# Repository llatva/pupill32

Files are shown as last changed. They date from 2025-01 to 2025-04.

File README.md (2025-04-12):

# pu(rple)pill32
## Compact and inexpensive USB-C development board for PY32F030 (TSSOP20) 32-bit MCU

RevA had some glitches, please refer to changelog in the revB schematic or below.
RevB tested to be functional, and can be flash-programmed over USB (see bootloader access below).

## Features

* development/evaluation board for Pyua PY32F030F1xP6 MCU (TSSOP20)
* USB serial (CH340N, ESD protection)
* USB bootloader support (e.g. puyaisp.py from MCU-Flash-Tools /1/)
* 48 MHz operation with internal oscillator
* option for 32.768 kHz crystal (if used, pins PA9 and PA10 reserved)
* all peripheral pins available
* SWD header for programming (by using USB bootloader for flashing, those pins can be configured for other purposes**)
* 3V3 linear regulator; 3V3 logic levels
* powered from USB (SMD fuse for overcurrent protection)
* PWR LED and user-programmable USR led (activated by solder bridge)
* RESET and BOOT buttons

**) In that case, if you don't need pull-ups for your signals, do not populate R11-R12.

## Bootloader access

USB UART is connected to PA2/PA3 (TX/RX). To access bootloader (e.g. puyaisp.py /1/, USB-to-serial), either

* Disconnect USB cable, press and hold BOOT button then connect the cable.

OR 

* Connect USB cable, press and hold BOOT button and press and release RESET button

/1/ [https://github.com/wagiminator/MCU-Flash-Tools]

## Images

top
bottom

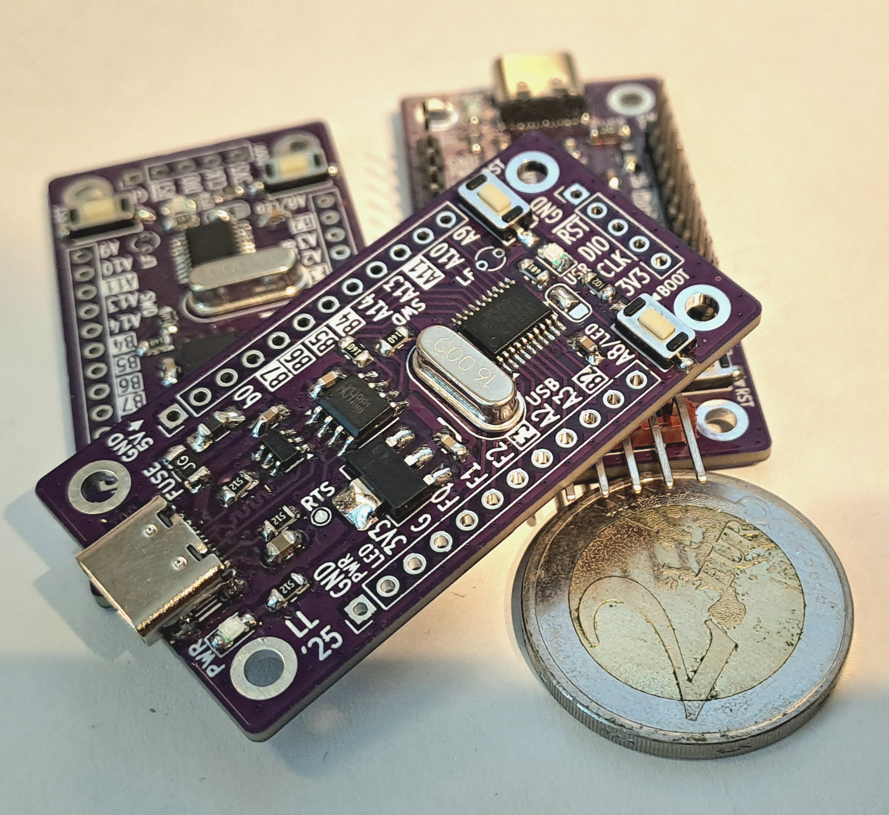
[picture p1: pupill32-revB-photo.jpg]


## Changelog revA --> revB

* added C19 (bug)
* swapped UART RX/TX (bug)
* added R1 (boot0 pulldown)
* R2 -> 5k1 (brightness)
* C20 tantalum
* SWD resistors R9-R12 added

## Independent project -- no affiliation or endorsement

This project is no way affiliated with Puya Semiconductor or any other commercial body. This is an indie evaluation board designed and built by a hobbyist. You may use this open hardware design, at your own risk, according to its license conditions, see the following chapter. 

## References

/2/ [J. Carlson: The cheapest flash microcontroller you can buy is actually an ARM CORTEX-M0+](https://jaycarlson.net/2023/02/04/the-cheapest-flash-microcontroller-you-can-buy-is-actually-an-arm-cortex-m0/)

/3/ [OpenPuya -- py32.org](https://py32.org/en/)

## License

This board is licensed under CERN Open Hardware License, version 2, CERN-OHL-W (weakly reciprocal). 

Please refer to LICENSE file for more information.

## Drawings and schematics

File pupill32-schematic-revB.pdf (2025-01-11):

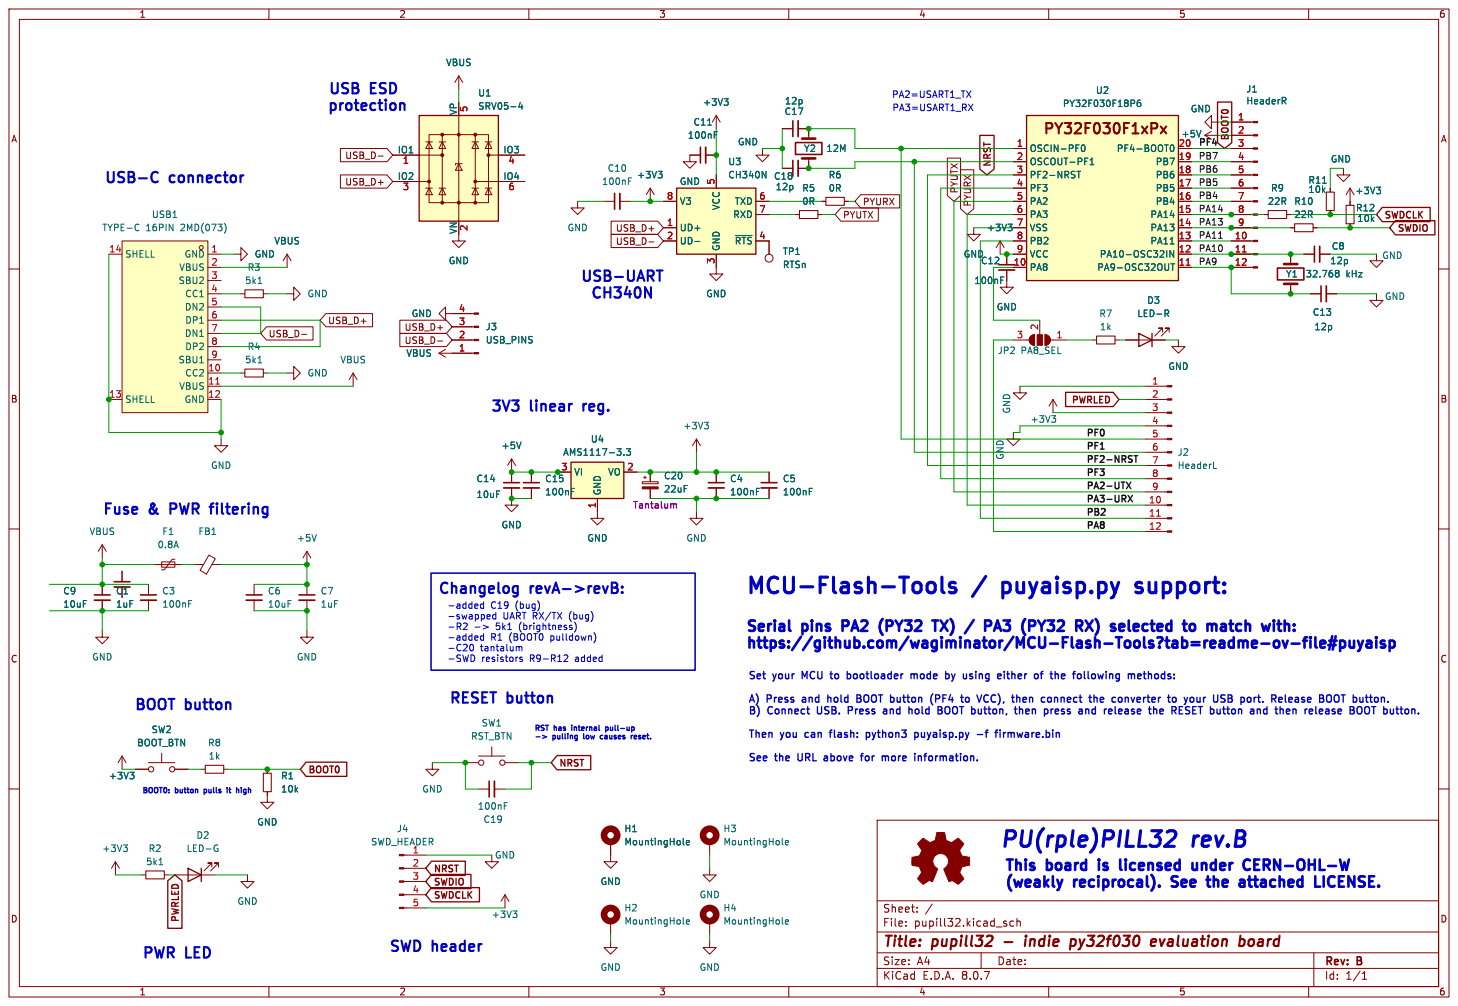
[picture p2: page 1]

PA2=USART1_TX Serial pins PA2 (PY32 TX) / PA3 (PY32 RX) selected to match with:

Changelog revA->revB: BOOT0: button pulls it high Fuse & PWR filtering
10uF GND

https://github.com/wagiminator/MCU-Flash-Tools?tab=readme-ov-file#puyaisp

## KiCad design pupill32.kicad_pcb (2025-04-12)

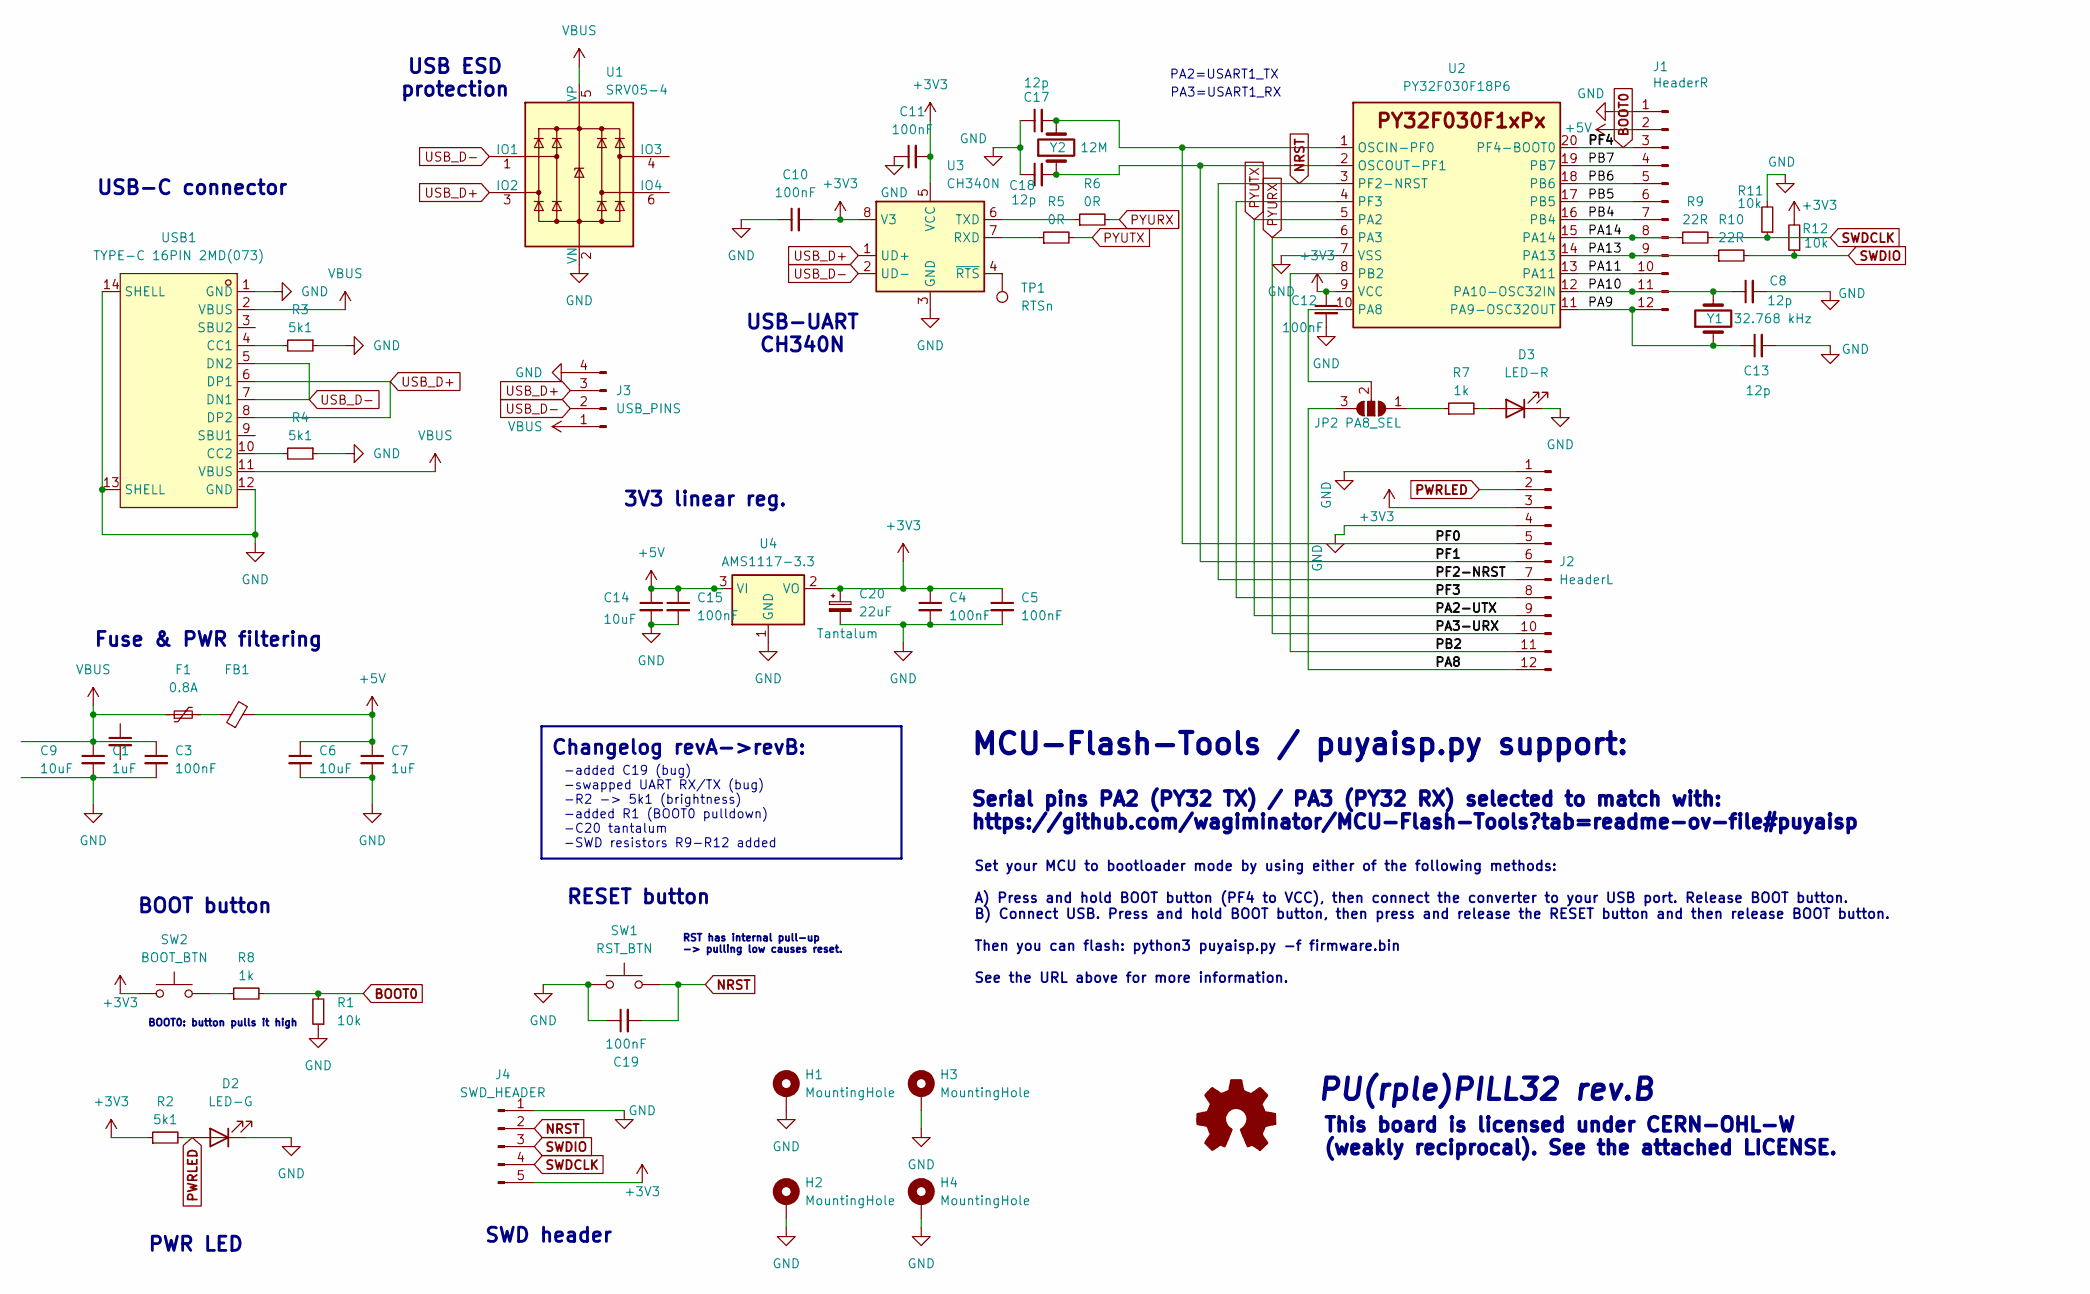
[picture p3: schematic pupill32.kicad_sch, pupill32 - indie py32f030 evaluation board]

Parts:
C1, C7: 1uF; C_0805_2012Metric_Pad1.18x1.45mm_HandSolder
C3, C4, C5, C10, C11, C12, C15, C19: 100nF; C_0805_2012Metric_Pad1.18x1.45mm_HandSolder
C6, C9, C14: 10uF; C_0805_2012Metric_Pad1.18x1.45mm_HandSolder
C8, C13, C17, C18: 12p; C_0805_2012Metric_Pad1.18x1.45mm_HandSolder
C20: 22uF; CP_EIA-3528-21_Kemet-B_Pad1.50x2.35mm_HandSolder
D2: LED-G; LED_0805_2012Metric_Pad1.15x1.40mm_HandSolder
D3: LED-R; LED_0805_2012Metric_Pad1.15x1.40mm_HandSolder
F1: 0.8A; Fuse_1206_3216Metric_Pad1.42x1.75mm_HandSolder
FB1: L_1206_3216Metric_Pad1.42x1.75mm_HandSolder
H1, H2, H3, H4: MountingHole; MountingHole_2.7mm_M2.5_ISO7380_Pad
J1: HeaderR; PinHeader_1x12_P2.54mm_Vertical
J2: HeaderL; PinHeader_1x12_P2.54mm_Vertical
J3: USB_PINS; PinHeader_1x04_P2.00mm_Vertical
J4: SWD_HEADER; PinHeader_1x05_P2.54mm_Vertical
JP2: PA8_SEL; SolderJumper-3_P1.3mm_Open_RoundedPad1.0x1.5mm
R1, R11, R12: 10k; R_0805_2012Metric_Pad1.20x1.40mm_HandSolder
R2, R3, R4: 5k1; R_0805_2012Metric_Pad1.20x1.40mm_HandSolder
R5, R6: 0R; R_0805_2012Metric_Pad1.20x1.40mm_HandSolder
R7, R8: 1k; R_0805_2012Metric_Pad1.20x1.40mm_HandSolder
R9, R10: 22R; R_0805_2012Metric_Pad1.20x1.40mm_HandSolder
SW1: RST_BTN; SW-SMD_L6.0-W3.5-LS8.2
SW2: BOOT_BTN; SW-SMD_L6.0-W3.5-LS8.2
TP1: RTSn; TestPoint_Pad_D1.0mm
U1: SRV05-4; SOT-23-6
U2: PY32F030F18P6; TSSOP-20_4.4x6.5mm_P0.65mm
U3: CH340N; SOP-8_3.9x4.9mm_P1.27mm
U4: AMS1117-3.3; SOT-223-3_TabPin2
USB1: TYPE-C 16PIN 2MD(073); USB-C-SMD_TYPE-C-6PIN-2MD-073; LCSC Part C2765186
Y1: 32.768 kHz; Crystal_Round_D2.0mm_Vertical
Y2: 12M; Crystal_HC49-4H_Vertical

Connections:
+3V3: C4.1, C5.1, C10.2, C11.2, C12.1, C20.1, J2.3, J4.5, R2.1, R12.2, SW2.1, U2.9 (VCC), U3.5 (VCC), U3.8 (V3), U4.2 (VO)
+5V: C6.1, C7.1, C14.1, C15.1, FB1.2, J1.2, U4.3 (VI)
/PA8: J2.12, JP2.3 (B)
/PA9: C13.1, J1.12, U2.11 (PA9-OSC32OUT), Y1.1
/PA10: C8.1, J1.11, U2.12 (PA10-OSC32IN), Y1.2
/PA11: J1.10, U2.13 (PA11)
/PA13: J1.9, R10.1, U2.14 (PA13)
/PA14: J1.8, R9.1, U2.15 (PA14)
/PB2: J2.11, U2.8 (PB2)
/PB4: J1.7, U2.16 (PB4)
/PB5: J1.6, U2.17 (PB5)
/PB6: J1.5, U2.18 (PB6)
/PB7: J1.4, U2.19 (PB7)
/PF0: C17.2, J2.5, U2.1 (OSCIN-PF0), Y2.2
/PF1: C18.2, J2.6, U2.2 (OSCOUT-PF1), Y2.1
/PF3: J2.8, U2.4 (PF3)
BOOT0: J1.3, R1.2, R8.2, U2.20 (PF4-BOOT0)
GND: C1.2, C3.2, C4.2, C5.2, C6.2, C7.2, C8.2, C10.1, C11.1, C12.2, C13.2, C14.2, C15.2, C17.1, C18.1, C19.1, C20.2, D2.1 (K), D3.1 (K), H1.1, H2.1, H3.1, H4.1, J1.1, J2.1, J2.4, J3.4, J4.1, R1.1, R3.1, R4.1, R11.2, SW1.1, U1.2 (VN), U2.7 (VSS), U3.3 (GND), U4.1 (GND), USB1.1 (GND), USB1.12 (GND), USB1.13 (SHELL), USB1.14 (SHELL)
NRST: C19.2, J2.7, J4.2, SW1.2, U2.3 (PF2-NRST)
unnamed: D3.2 (A), R7.2
unnamed: F1.2, FB1.1
unnamed: JP2.1 (A), R7.1
unnamed: JP2.2 (C), U2.10 (PA8)
unnamed: R8.1, SW2.2
unnamed: R5.1, U3.7 (RXD)
unnamed: R6.1, U3.6 (TXD)
unnamed: TP1.1, U3.4 (~RTS)
unnamed: R3.2, USB1.4 (CC1)
unnamed: R4.2, USB1.10 (CC2)
PWRLED: D2.2 (A), J2.2, R2.2
PYURX: J2.10, R6.2, U2.6 (PA3)
PYUTX: J2.9, R5.2, U2.5 (PA2)
SWDCLK: J4.4, R9.2, R11.1
SWDIO: J4.3, R10.2, R12.1
USB_D+: J3.3, U1.3 (IO2), U3.1 (UD+), USB1.6 (DP1), USB1.8 (DP2)
USB_D-: J3.2, U1.1 (IO1), U3.2 (UD-), USB1.5 (DN2), USB1.7 (DN1)
VBUS: C1.1, C3.1, F1.1, J3.1, U1.5 (VP), USB1.2 (VBUS), USB1.11 (VBUS)

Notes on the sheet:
-added C19 (bug) -swapped UART RX/TX (bug) -R2 -> 5k1 (brightness) -added R1 (BOOT0 pulldown) -C20 tantalum -SWD resistors R9-R12 added
RESET button
This board is licensed under CERN-OHL-W (weakly reciprocal). See the attached LICENSE.
Serial pins PA2 (PY32 TX) / PA3 (PY32 RX) selected to match with: https://github.com/wagiminator/MCU-Flash-Tools?tab=readme-ov-file#puyaisp
PA3=USART1_RX
3V3 linear reg.
Fuse & PWR filtering
MCU-Flash-Tools / puyaisp.py support:
USB-C connector
PWR LED
USB ESD protection
PA2=USART1_TX
RST has internal pull-up -> pulling low causes reset.
Changelog revA->revB:
BOOT button
USB-UART CH340N
BOOT0: button pulls it high
PU(rple)PILL32 rev.B
Set your MCU to bootloader mode by using either of the following methods: A) Press and hold BOOT button (PF4 to VCC), then connect the converter to your USB port. Release BOOT button. B) Connect USB. Press and hold BOOT button, then press and release the RESET button and then release BOOT button. T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
SWD header

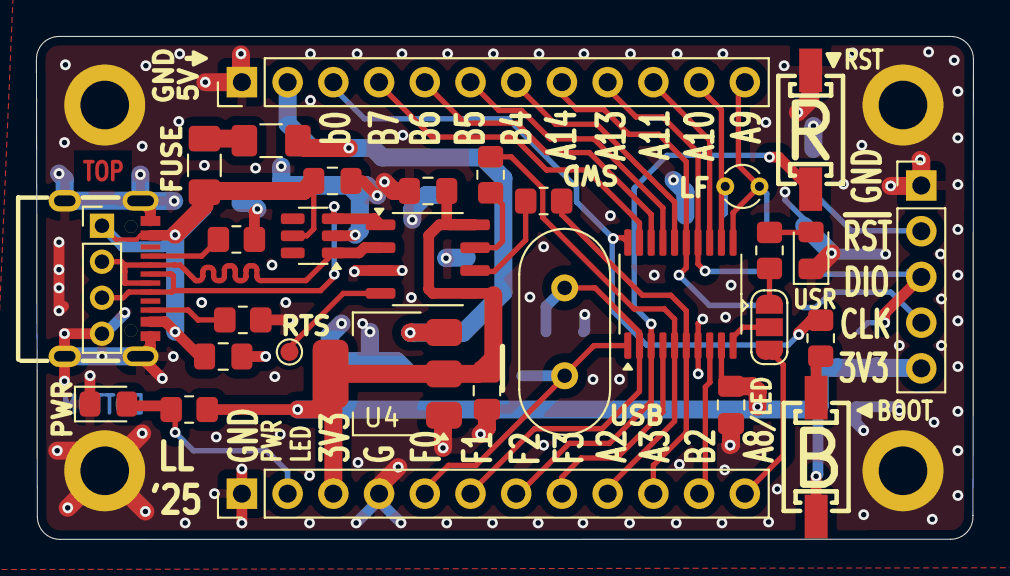
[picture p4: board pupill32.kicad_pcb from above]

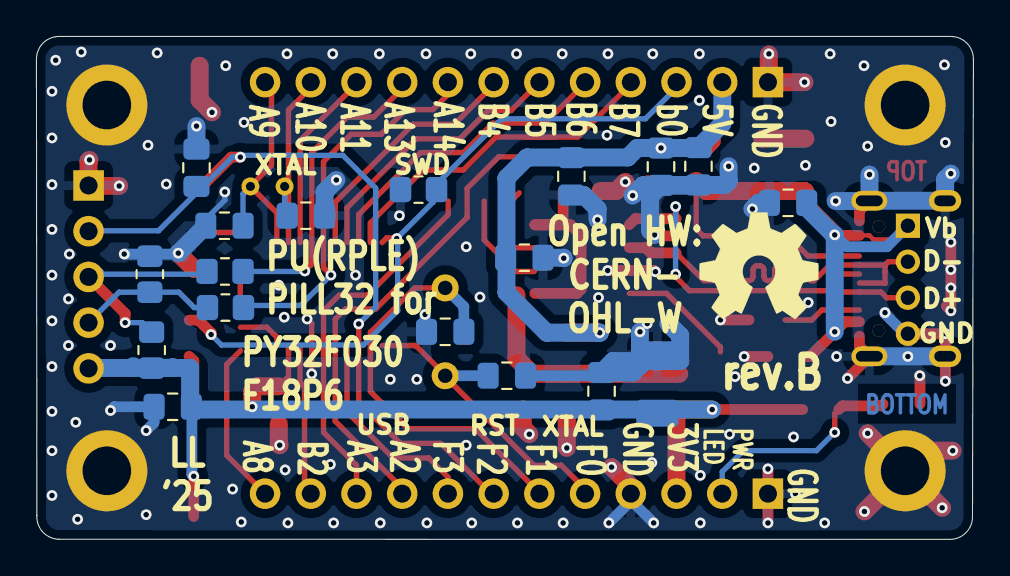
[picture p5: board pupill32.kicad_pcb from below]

Board: 2 copper layers, 52.1 x 27.9 mm, 54 parts (19 on the bottom side), 37 nets.

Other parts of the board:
OHW: OSHW-Symbol_6.7x6mm_SilkScreen

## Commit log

2024-07-22 first commit to repo
    [pypill32.kicad_pcb, pypill32.kicad_sch]
2024-07-22 intermediate save
    [pypill32.kicad_pcb, pypill32.kicad_sch]
2024-07-22 switch footprint and 3d
    [pypill32.kicad_pcb, pypill32.kicad_sch]
2024-07-22 some progress
    [pypill32.kicad_pcb, pypill32.kicad_sch]
2024-07-22 to be continued
    [pypill32.kicad_pcb, pypill32.kicad_sch]
2024-07-23 silks and some routing, to be continued
    [pypill32.kicad_pcb, pypill32.kicad_sch]
2024-07-23 almost ready
    [pypill32.kicad_pcb, pypill32.kicad_sch]
2024-07-24 checking and verifying still
    [pypill32.kicad_pcb, pypill32.kicad_sch]
2024-07-24 some fine-tuning
    [pypill32.kicad_pcb]
2024-07-24 schema to pdf
    [pypill32.kicad_sch]
2024-07-24 note text edit
    [pypill32.kicad_sch]
2024-07-24 fix uart pins
    [pypill32.kicad_pcb, pypill32.kicad_sch]
2024-07-24 added pad for RTS pin
    [pypill32.kicad_pcb, pypill32.kicad_sch]
2024-08-01 added HF crystal
    [pypill32.kicad_pcb, pypill32.kicad_sch]
2024-08-01 texts edit
    [pypill32.kicad_pcb]
2024-08-01 minor text position fix
    [pypill32.kicad_pcb]
2024-08-01 added GND via
    [pypill32.kicad_pcb]
2024-12-14 project rename
    [pupill32.kicad_pcb, pupill32.kicad_sch]
2024-12-14 project rename, part2
    [pupill32.kicad_sch, pypill32.kicad_pcb, pypill32.kicad_sch]
2024-12-14 project rename, part3
    [pupill32.kicad_pcb, pupill32.kicad_sch]
2024-12-15 update schematic, rename file
2025-01-03 revA errata -> revB
    [pupill32.kicad_pcb, pupill32.kicad_sch]
2025-01-03 schema update (stylish changes, no content changes)
    [pupill32.kicad_sch]
2025-01-04 R1 boot0 pulldown
    [pupill32.kicad_pcb, pupill32.kicad_sch]
2025-01-04 schema changelog update
    [pupill32.kicad_sch]
2025-01-10 SWD resistors, changelog update
    [pupill32.kicad_pcb, pupill32.kicad_sch]
2025-01-10 minor tuning
    [pupill32.kicad_pcb]
2025-01-10 tantalum silk
    [pupill32.kicad_pcb]
2025-01-10 bot silks
    [pupill32.kicad_pcb]
2025-01-11 SWCLK pulled down (corrected)
    [pupill32.kicad_pcb, pupill32.kicad_sch]
2025-04-12 README update, photo of revB
    [pupill32.kicad_pcb]
